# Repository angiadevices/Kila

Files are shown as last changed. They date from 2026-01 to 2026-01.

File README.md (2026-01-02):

**!!THIS IS CURRENTLY ENTIRELY UNTESTED!!**

**TODO:** Test PCB design.
Make a better PCB layout because this one is just a complete mess. But if it works...?

## Kila

Kila | किला: Fort/Castle

A Eurorack adaptation of the [Bastl Kastle](https://bastl-instruments.com/instruments/kastle).

This is almost entirely based specifically on the [Sluisbrinkie Kepler](https://github.com/niektb/sluisbrinkie-eurorack-published/tree/main/Sluisbrinkie%20Kepler). There were no hardware files available so I decided to venture into laying out my own.

14HP</br>
Eschews the switches of the original for purely potentiometers and mono jacks.</br>
Includes header for power via external +5VDC source.

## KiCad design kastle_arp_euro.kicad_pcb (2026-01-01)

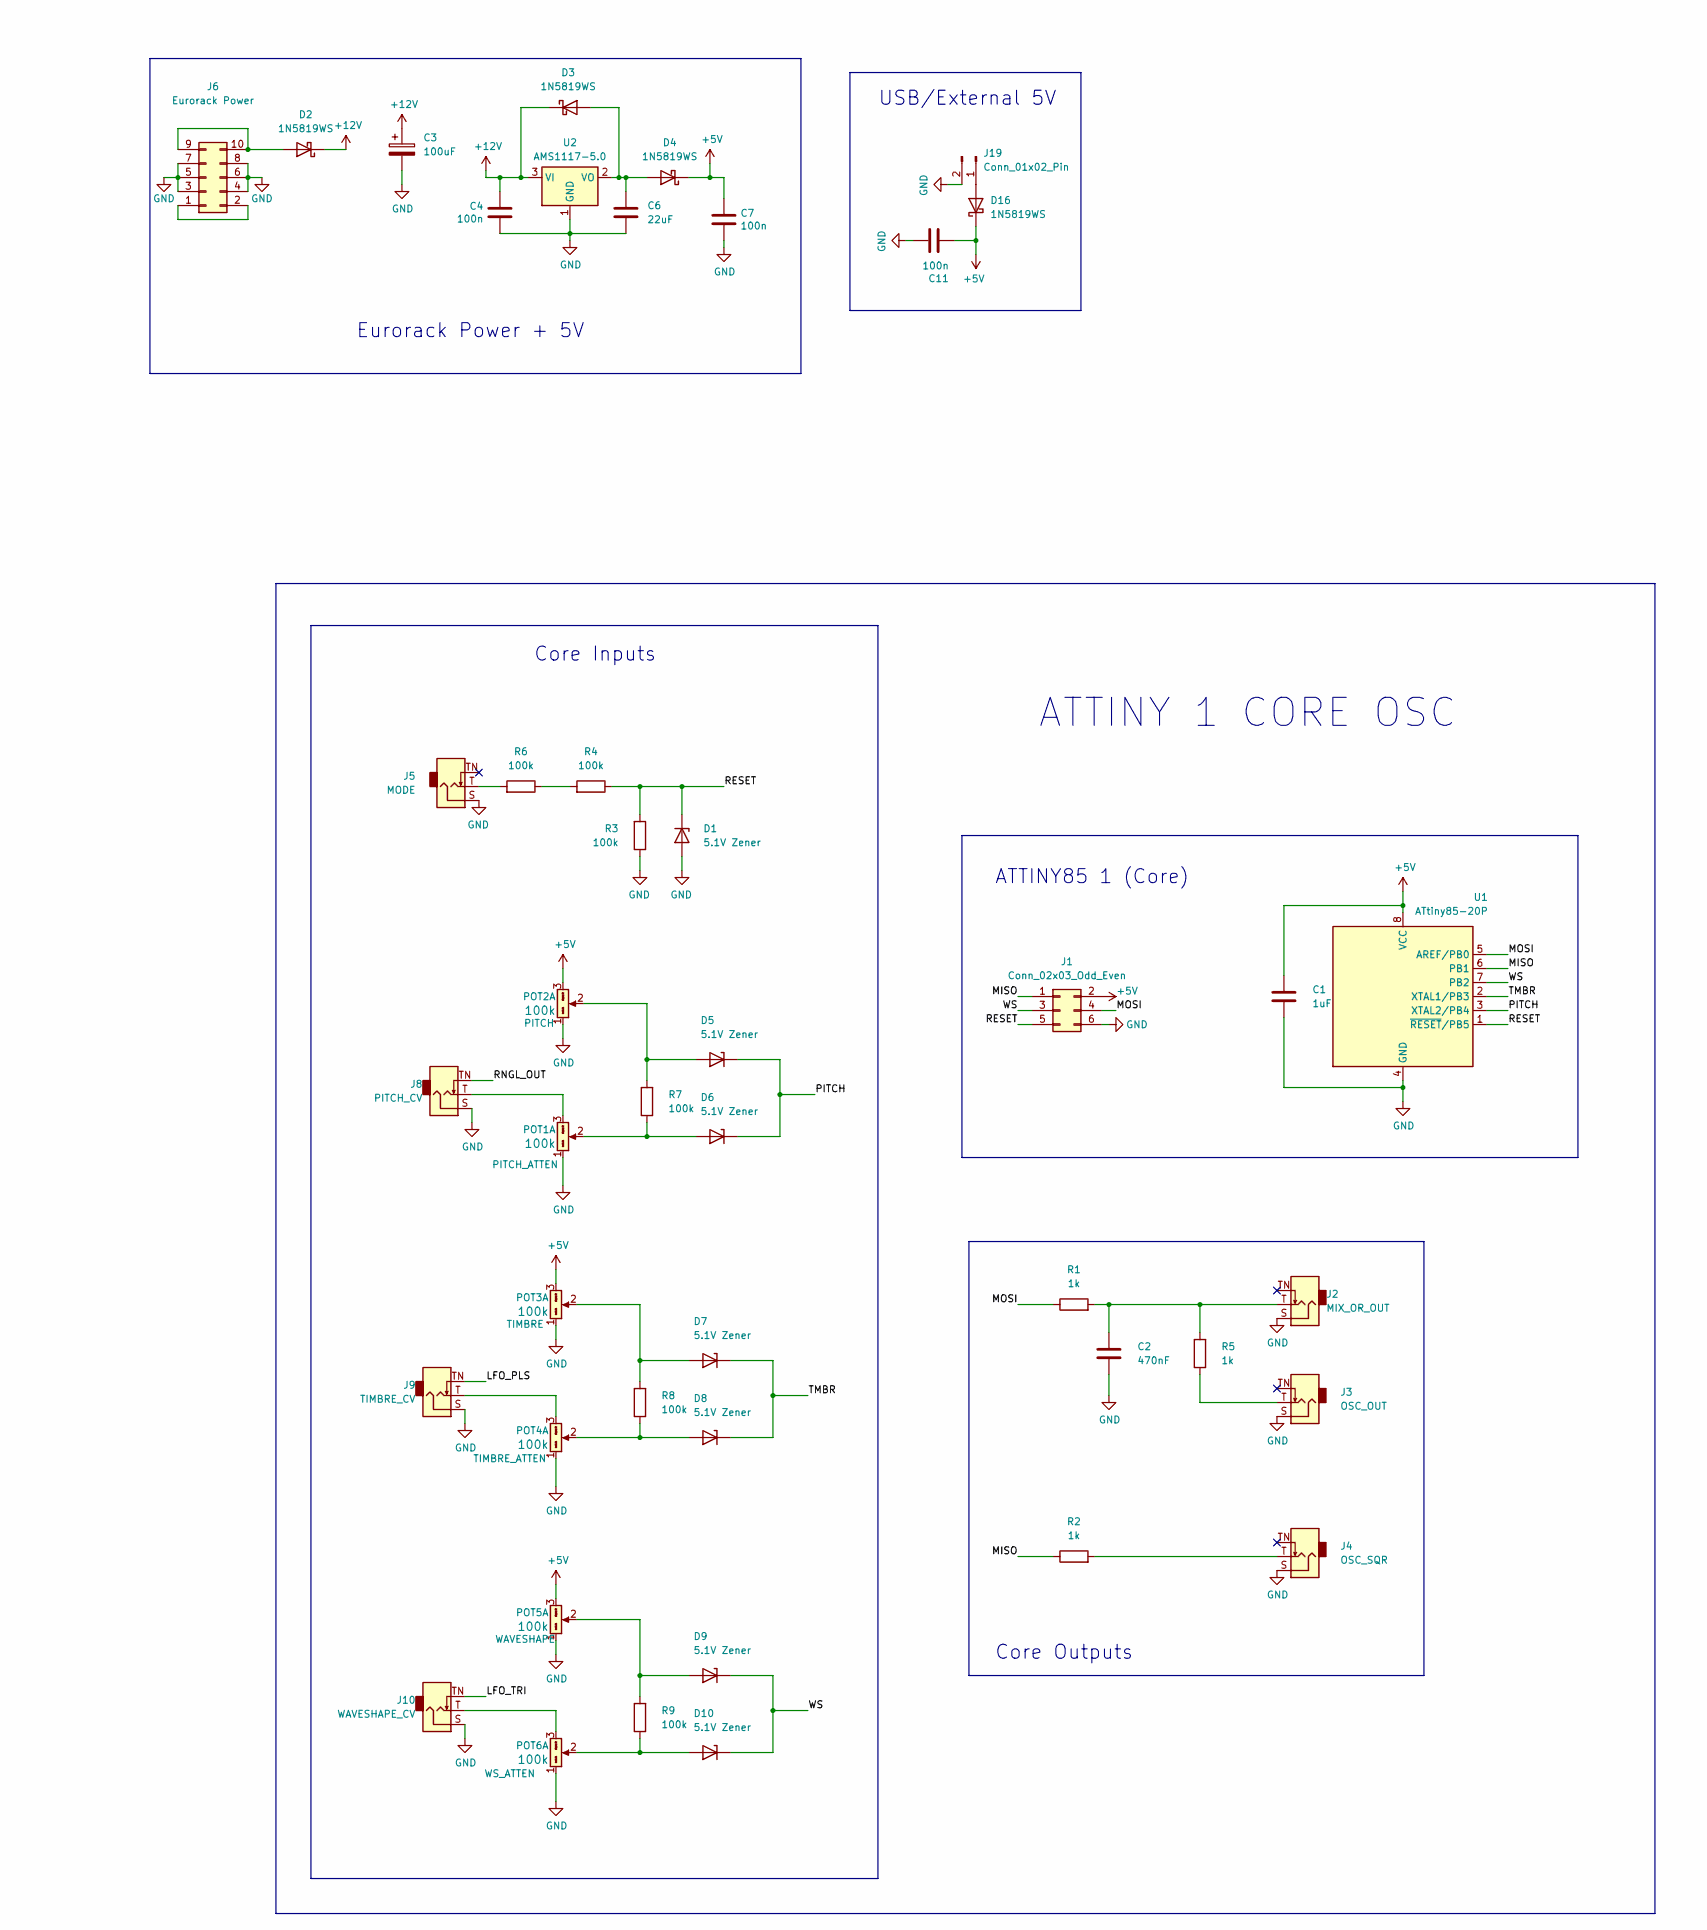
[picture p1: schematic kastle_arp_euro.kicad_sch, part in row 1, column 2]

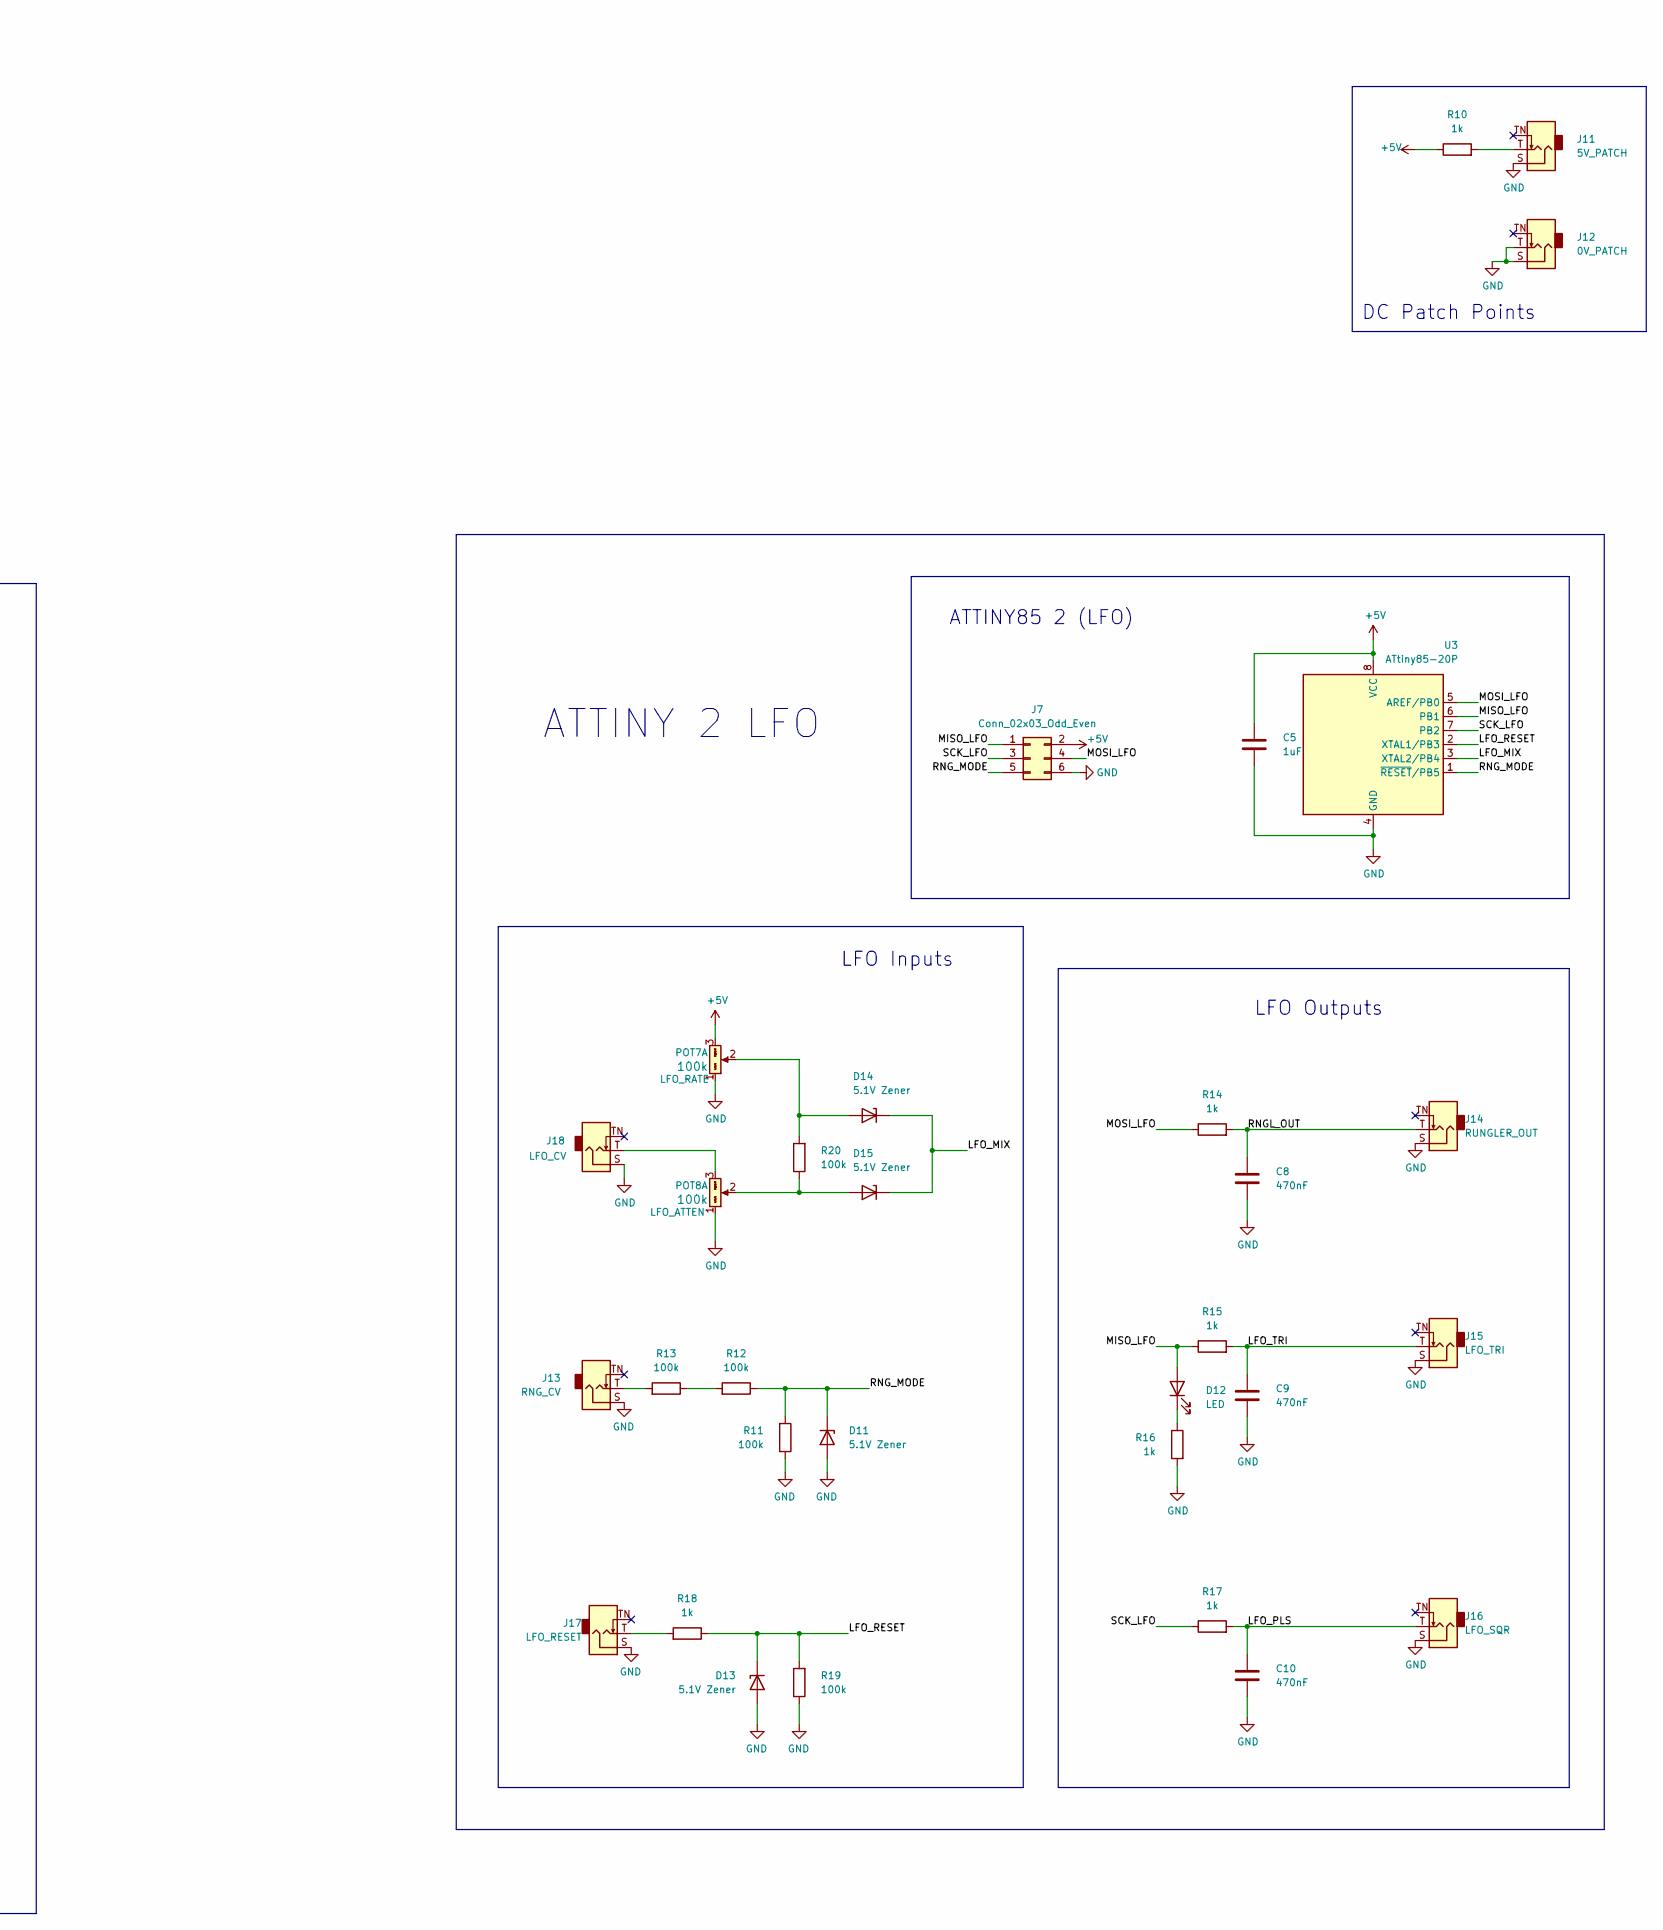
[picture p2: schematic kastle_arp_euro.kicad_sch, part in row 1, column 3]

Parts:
C1, C5: 1uF; C_0805_2012Metric_Pad1.18x1.45mm_HandSolder
C2, C8, C9, C10: 470nF; C_0805_2012Metric_Pad1.18x1.45mm_HandSolder
C3: 100uF; CP_Radial_D6.3mm_P2.50mm
C4, C7, C11: 100n; C_0805_2012Metric_Pad1.18x1.45mm_HandSolder
C6: 22uF; C_1206_3216Metric_Pad1.33x1.80mm_HandSolder
D1, D5, D6, D7, D8, D9, D10, D11, D13, D14, D15: 5.1V Zener; D_MiniMELF_Handsoldering
D2, D3, D4, D16: 1N5819WS; D_SOD-323_HandSoldering
D12: LED; LED_D3.0mm
J1, J7: Conn_02x03_Odd_Even; PinHeader_2x03_P2.54mm_Vertical
J2: MIX_OR_OUT; Jack_3.5mm_QingPu_WQP-PJ398SM_Vertical_CircularHoles
J3: OSC_OUT; Jack_3.5mm_QingPu_WQP-PJ398SM_Vertical_CircularHoles
J4: OSC_SQR; Jack_3.5mm_QingPu_WQP-PJ398SM_Vertical_CircularHoles
J5: MODE; Jack_3.5mm_QingPu_WQP-PJ398SM_Vertical_CircularHoles
J6: Eurorack Power; IDC-Header_2x05_P2.54mm_Vertical
J8: PITCH_CV; Jack_3.5mm_QingPu_WQP-PJ398SM_Vertical_CircularHoles
J9: TIMBRE_CV; Jack_3.5mm_QingPu_WQP-PJ398SM_Vertical_CircularHoles
J10: WAVESHAPE_CV; Jack_3.5mm_QingPu_WQP-PJ398SM_Vertical_CircularHoles
J11: 5V_PATCH; Jack_3.5mm_QingPu_WQP-PJ398SM_Vertical_CircularHoles
J12: 0V_PATCH; Jack_3.5mm_QingPu_WQP-PJ398SM_Vertical_CircularHoles
J13: RNG_CV; Jack_3.5mm_QingPu_WQP-PJ398SM_Vertical_CircularHoles
J14: RUNGLER_OUT; Jack_3.5mm_QingPu_WQP-PJ398SM_Vertical_CircularHoles
J15: LFO_TRI; Jack_3.5mm_QingPu_WQP-PJ398SM_Vertical_CircularHoles
J16: LFO_SQR; Jack_3.5mm_QingPu_WQP-PJ398SM_Vertical_CircularHoles
J17: LFO_RESET; Jack_3.5mm_QingPu_WQP-PJ398SM_Vertical_CircularHoles
J18: LFO_CV; Jack_3.5mm_QingPu_WQP-PJ398SM_Vertical_CircularHoles
J19: Conn_01x02_Pin; JST_EH_B2B-EH-A_1x02_P2.50mm_Vertical
POT1: PITCH_ATTEN; Potentiometer_Alpha_RD901F-40-00D_Single_Vertical; Part Number RV16AF-4A-15FW-B100K-3
POT2: PITCH; Potentiometer_Alpha_RD901F-40-00D_Single_Vertical; Part Number RV16AF-4A-15FW-B100K-3
POT3: TIMBRE; Potentiometer_Alpha_RD901F-40-00D_Single_Vertical; Part Number RV16AF-4A-15FW-B100K-3
POT4: TIMBRE_ATTEN; Potentiometer_Alpha_RD901F-40-00D_Single_Vertical; Part Number RV16AF-4A-15FW-B100K-3
POT5: WAVESHAPE; Potentiometer_Alpha_RD901F-40-00D_Single_Vertical; Part Number RV16AF-4A-15FW-B100K-3
POT6: WS_ATTEN; Potentiometer_Alpha_RD901F-40-00D_Single_Vertical; Part Number RV16AF-4A-15FW-B100K-3
POT7: LFO_RATE; Potentiometer_Alpha_RD901F-40-00D_Single_Vertical; Part Number RV16AF-4A-15FW-B100K-3
POT8: LFO_ATTEN; Potentiometer_Alpha_RD901F-40-00D_Single_Vertical; Part Number RV16AF-4A-15FW-B100K-3
R1, R2, R5, R10, R14, R15, R16, R17, R18: 1k; R_0805_2012Metric_Pad1.20x1.40mm_HandSolder
R3, R4, R6, R7, R8, R9, R11, R12, R13, R19, R20: 100k; R_0805_2012Metric_Pad1.20x1.40mm_HandSolder
U1, U3: ATtiny85-20P; SOIC-8_3.9x4.9mm_P1.27mm
U2: AMS1117-5.0; SOT-223-3_TabPin2

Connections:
+5V: C1.1, C5.1, C7.1, C11.1, D4.1 (K), D16.1 (K), J1.2, J7.2, POT2.3 (Right), POT3.3 (Right), POT5.3 (Right), POT7.3 (Right), R10.1, U1.8 (VCC), U3.8 (VCC)
+12V: C3.1, C4.1, D2.1 (K), D3.1 (K), U2.3 (VI)
/LFO_MIX: D14.1 (K), D15.1 (K), U3.3 (XTAL2/PB4)
/LFO_PLS: C10.1, J9.TN, J16.T, R17.2
/LFO_RESET: D13.1 (K), R18.1, R19.2, U3.2 (XTAL1/PB3)
/LFO_TRI: C9.1, J10.TN, J15.T, R15.2
/MISO: J1.1, R2.1, U1.6 (PB1)
/MISO_LFO: D12.2 (A), J7.1, R15.1, U3.6 (PB1)
/MOSI: J1.4, R1.1, U1.5 (AREF/PB0)
/MOSI_LFO: J7.4, R14.1, U3.5 (AREF/PB0)
/PITCH: D5.1 (K), D6.1 (K), U1.3 (XTAL2/PB4)
/RESET: D1.1 (K), J1.5, R3.2, R4.1, U1.1 (~RESET/PB5)
/RNGL_OUT: C8.1, J8.TN, J14.T, R14.2
/RNG_MODE: D11.1 (K), J7.5, R11.2, R12.1, U3.1 (~RESET/PB5)
/SCK_LFO: J7.3, R17.1, U3.7 (PB2)
/TMBR: D7.1 (K), D8.1 (K), U1.2 (XTAL1/PB3)
/WS: D9.1 (K), D10.1 (K), J1.3, U1.7 (PB2)
GND: C1.2, C2.2, C3.2, C4.2, C5.2, C6.2, C7.2, C8.2, C9.2, C10.2, C11.2, D1.2 (A), D11.2 (A), D13.2 (A), J1.6, J2.S, J3.S, J4.S, J5.S, J6.3, J6.4, J6.5, J6.6, J6.7, J6.8, J7.6, J8.S, J9.S, J10.S, J11.S, J12.S, J12.T, J13.S, J14.S, J15.S, J16.S, J17.S, J18.S, J19.2, POT1.1 (Left), POT2.1 (Left), POT3.1 (Left), POT4.1 (Left), POT5.1 (Left), POT6.1 (Left), POT7.1 (Left), POT8.1 (Left), R3.1, R11.1, R16.2, R19.1, U1.4 (GND), U2.1 (GND), U3.4 (GND)
unnamed: C2.1, J2.T, R1.2, R5.2
unnamed: D2.2 (A), J6.9, J6.10
unnamed: C6.1, D3.2 (A), D4.2 (A), U2.2 (VO)
unnamed: D5.2 (A), POT2.2 (Center), R7.2
unnamed: D6.2 (A), POT1.2 (Center), R7.1
unnamed: D7.2 (A), POT3.2 (Center), R8.2
unnamed: D8.2 (A), POT4.2 (Center), R8.1
unnamed: D9.2 (A), POT5.2 (Center), R9.2
unnamed: D10.2 (A), POT6.2 (Center), R9.1
unnamed: D12.1 (K), R16.1
unnamed: D14.2 (A), POT7.2 (Center), R20.2
unnamed: D15.2 (A), POT8.2 (Center), R20.1
unnamed: D16.2 (A), J19.1
unnamed: J3.T, R5.1
unnamed: J4.T, R2.2
unnamed: J5.T, R6.2
unnamed: J6.1, J6.2
unnamed: J11.T, R10.2
unnamed: J13.T, R13.2
unnamed: J17.T, R18.2
unnamed: J8.T, POT1.3 (Right)
unnamed: J9.T, POT4.3 (Right)
unnamed: J10.T, POT6.3 (Right)
unnamed: J18.T, POT8.3 (Right)
unnamed: R4.2, R6.1
unnamed: R12.2, R13.1

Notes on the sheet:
ATTINY 1 CORE OSC
USB/External 5V
Core Inputs
ATTINY85 2 (LFO)
ATTINY 2 LFO
LFO Inputs
Core Outputs
DC Patch Points
Eurorack Power + 5V
LFO Outputs
ATTINY85 1 (Core)

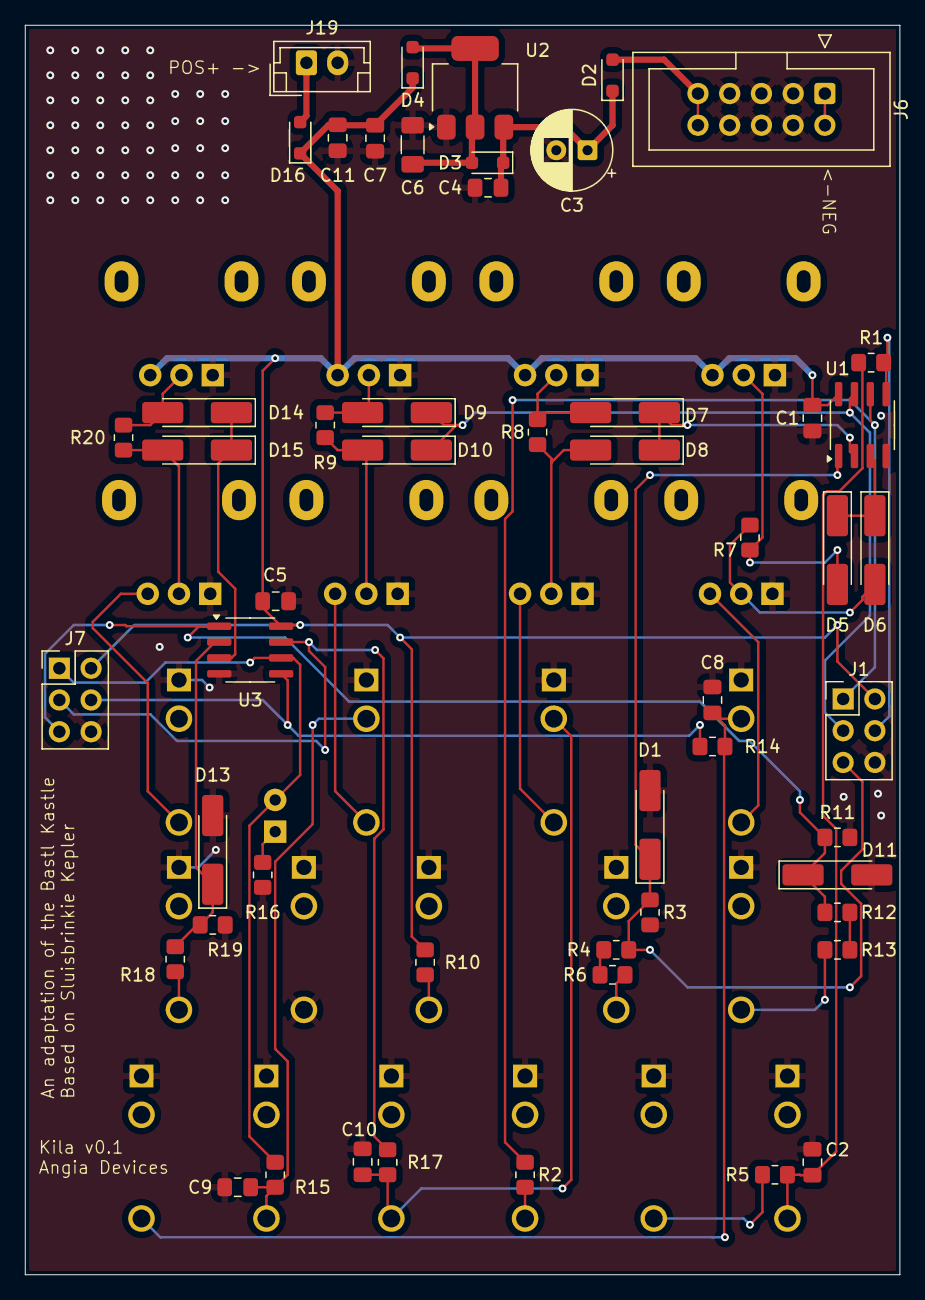
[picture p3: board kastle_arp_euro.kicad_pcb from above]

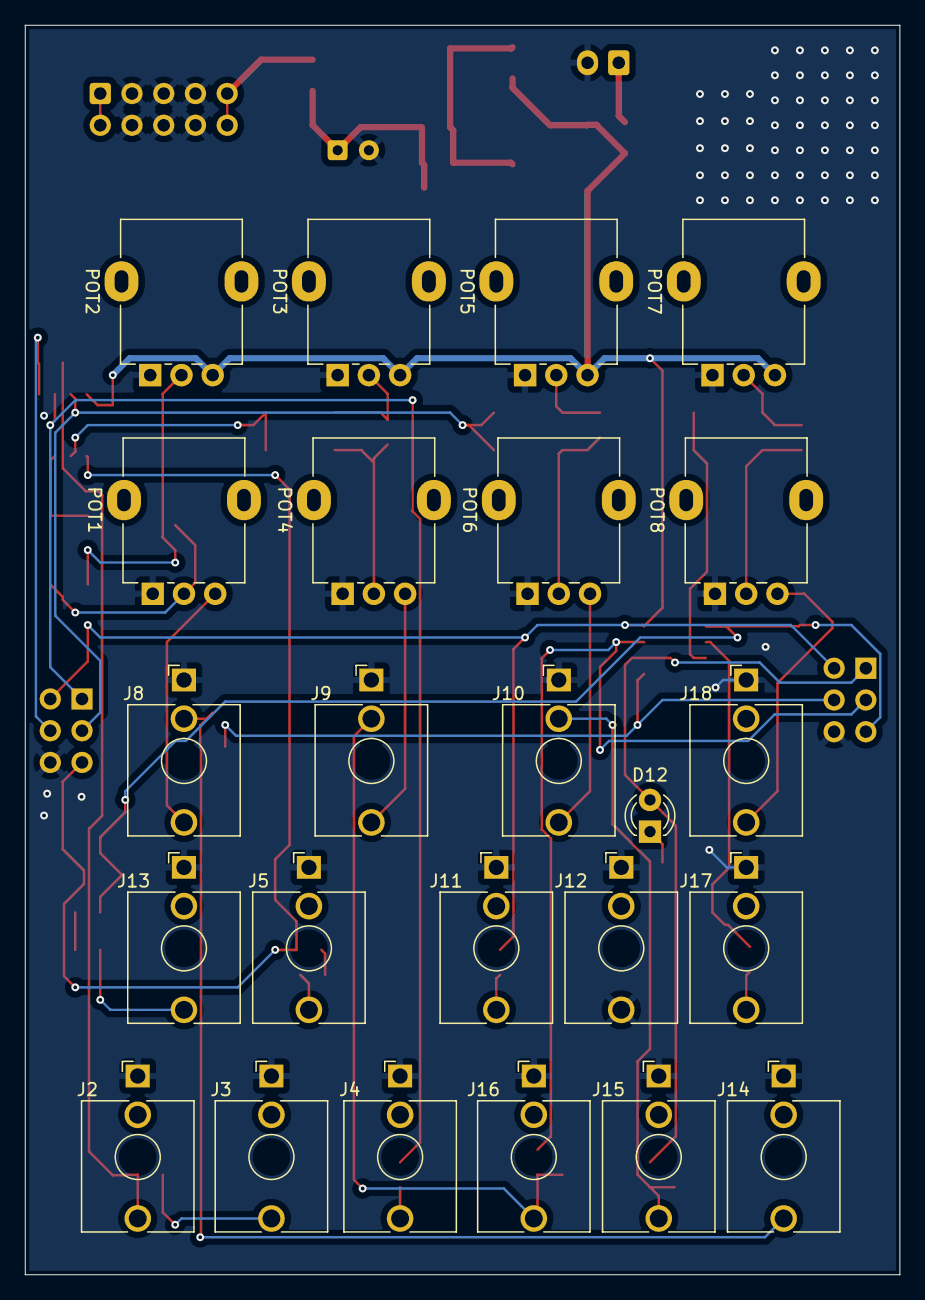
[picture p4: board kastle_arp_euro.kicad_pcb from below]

Board: 2 copper layers, 70.0 x 100.0 mm, 77 parts (24 on the bottom side), 44 nets.
